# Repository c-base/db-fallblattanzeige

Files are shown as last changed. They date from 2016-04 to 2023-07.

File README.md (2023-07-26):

# db-fallblattanzeige
A Fallblattfahrzielanzeige of the Deutsche Bahn

  - [Demo video](https://www.youtube.com/watch?v=KNWKdqRn240)
  - [Hackaday Project](https://hackaday.io/project/9070-fallblattfahrzielanzeige-of-s-bahn-berlin)

Daemon ist unter: https://github.com/c-base/db-fallblattanzeige-web/roloboxd/

Web-Interface-Repo ist unter: https://github.com/c-base/db-fallblattanzeige-web

Architektur-Skizze: https://www.dropbox.com/s/tzrm99uehv5yp3d/whiteboard.png?dl=0

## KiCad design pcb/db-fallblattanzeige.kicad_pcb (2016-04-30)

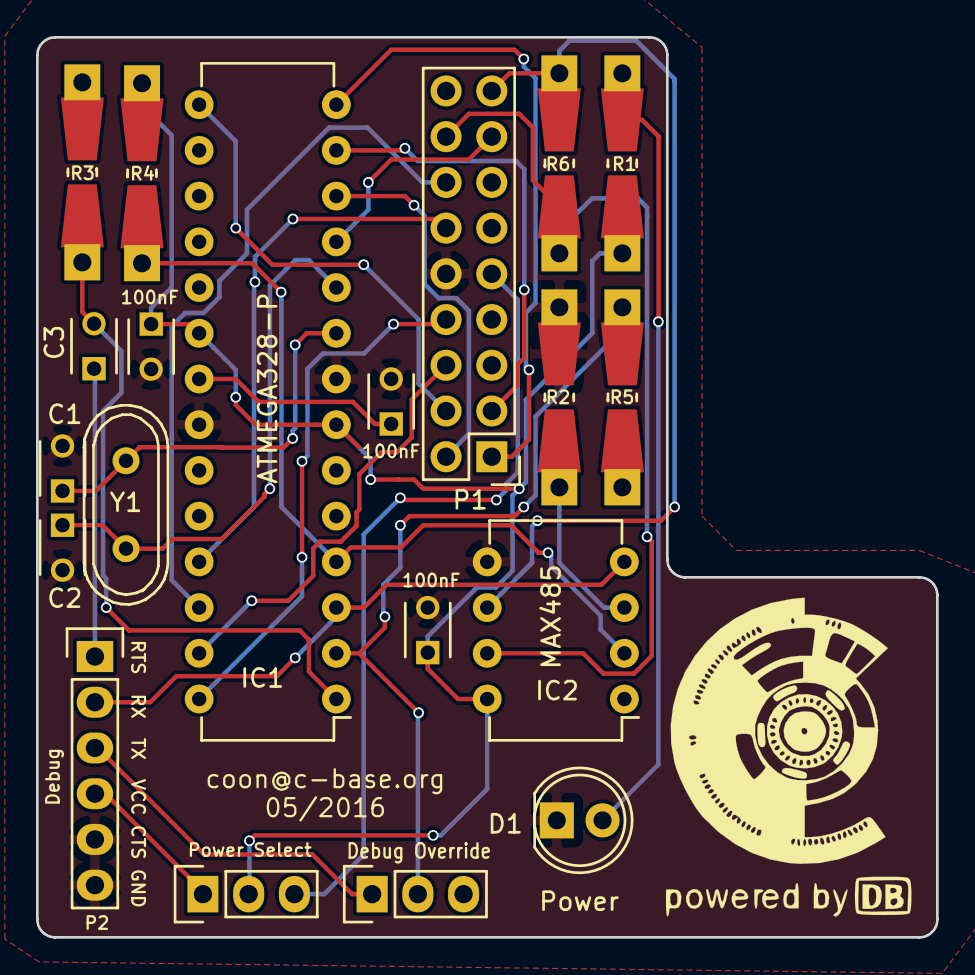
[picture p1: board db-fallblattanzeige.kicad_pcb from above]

Board: 2 copper layers, 50.0 x 50.0 mm, 20 parts (0 on the bottom side), 27 nets.

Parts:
100nF, 100nF#2, 100nF#3: C; C_Disc_D3_P2.5
C1, C2: 22pF; C_Disc_D3_P2.5
C3: 100nF; C_Disc_D3_P2.5
D1: Power LED (Green); LED-5MM
IC1: ATMEGA328-P; DIP-28_W7.62mm
IC2: MAX485; DIP-8_W7.62mm
JP1: Debug Override; Pin_Header_Straight_1x03
JP2: Power Select; Pin_Header_Straight_1x03
P1: ZiLOG_3562_FBM_V2.02
P2: FTDI_header; Pin_Header_Straight_1x06
R1: 150; Resistor_SMD+THTuniversal_0805to1206_RM10_HandSoldering
R2, R4: 4.7K; Resistor_SMD+THTuniversal_0805to1206_RM10_HandSoldering
R3: 10K; Resistor_SMD+THTuniversal_0805to1206_RM10_HandSoldering
R5: 1K; Resistor_SMD+THTuniversal_0805to1206_RM10_HandSoldering
R6: 120; Resistor_SMD+THTuniversal_0805to1206_RM10_HandSoldering
Y1: Crystal; Crystal_HC49-U_Vertical

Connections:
+5VA: JP2.1, P2.4
+5VD: JP2.3, P1.5
/BUS_MINUS: IC2.7, P1.11, R6.1
/BUS_PLUS: IC2.6, P1.9, R6.2
/IR_IN: IC1.11, P1.8
/Motor: IC1.15, P1.17
/PWR_IR1: IC1.26, P1.12
/PWR_IR2: IC1.25, P1.13
/SCL: IC1.28, P1.15
/SDA: IC1.27, P1.16
/SR_CP: IC1.13, P1.2
/SR_DATA: IC1.14, P1.1
/~SR_LATCH: IC1.12, P1.18
GND: 100nF.2, 100nF#2.2, 100nF#3.2, C1.2, C2.2, D1.1, IC1.8, IC1.22, IC2.5, P1.14, P2.5, P2.6, R2.2
unnamed: 100nF.1, IC1.21
unnamed: C1.1, IC1.9, Y1.1
unnamed: C2.1, IC1.10, Y1.2
unnamed: C3.1, P2.1
unnamed: C3.2, IC1.1, R3.2
unnamed: D1.2, R1.2
unnamed: IC1.2, JP1.2, R5.2
unnamed: IC1.3, IC2.4, P2.2
unnamed: IC1.4, IC2.2, R4.1
unnamed: IC1.5, IC2.3, R2.1
unnamed: IC2.1, R5.1
unnamed: JP1.1, P2.3
VCC: 100nF#2.1, 100nF#3.1, IC1.7, IC1.20, IC2.8, JP2.2, R1.1, R3.1, R4.2

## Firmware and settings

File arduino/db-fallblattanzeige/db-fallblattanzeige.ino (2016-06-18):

// DB-Fallblattanzeige 
// 18.06.2016
//
// Authors: uk, coon

// Pins
const int PIN_RS485_nRE  = 2;  // PD2 (Receive Enable)
const int PIN_RS485_DE   = 3;  // PD3 (Send Enable)
const int PIN_SENSORS_IN = 5;  // PD5 
const int PIN_SR_LATCH   = 6;  // PD6
const int PIN_SR_CP      = 7;  // PD7
const int PIN_SR_DATA    = 8;  // PB0
const int PIN_MOTOR      = 9;  // PB1
const int PIN_IR_ROTARY  = A2; // PC2
const int PIN_IR_ORIGIN  = A3; // PC3

// constants
const int I2C_EEPROM_ADDR = 0x50; // A0, A1, A2 are all on ground.
const int ORIGIN_OFFSET = 0; // TODO: read from EEPROM later!

enum SensorPhase {
  ODD,
  EVEN
};

int _myId = 0;

void waitForRotaryQuarters(SensorPhase phase, int quarters) {
  for(int i = 0; i < quarters; i++) {
    if(phase == EVEN) {    
      while(!digitalRead(PIN_SENSORS_IN)); // wait for first high
      while(digitalRead(PIN_SENSORS_IN));  // wait for low
      while(!digitalRead(PIN_SENSORS_IN)); // wait for second high 
    }
    else {
      while(digitalRead(PIN_SENSORS_IN));  // wait for first low
      while(!digitalRead(PIN_SENSORS_IN)); // wait for high
      while(digitalRead(PIN_SENSORS_IN));  // wait for second low
    }
  }
}

void flipCards(SensorPhase phase, int numCards) {
  digitalWrite(PIN_IR_ROTARY, HIGH);
  digitalWrite(PIN_MOTOR, LOW);
  
  for(int i = 0; i < numCards; i++)
    waitForRotaryQuarters(phase, 1);
    
  digitalWrite(PIN_MOTOR, HIGH);
  digitalWrite(PIN_IR_ROTARY, LOW);
}

void spinToOrigin(SensorPhase phase) {
  digitalWrite(PIN_IR_ORIGIN, HIGH);
  digitalWrite(PIN_MOTOR, LOW);

  while(digitalRead(PIN_SENSORS_IN));  // skip first high value
  while(!digitalRead(PIN_SENSORS_IN)); // wait for home  
  while(digitalRead(PIN_SENSORS_IN));  // wait for end of home
  
  digitalWrite(PIN_IR_ORIGIN, LOW);
  
  flipCards(phase, ORIGIN_OFFSET); // flip some additional cards, if needed
  
  digitalWrite(PIN_MOTOR, HIGH);
}

byte getDeviceBusAddress() {
  digitalWrite(PIN_SR_LATCH, LOW);
  delay(20);
  digitalWrite(PIN_SR_LATCH, HIGH);

  int address = 0;
  for(int i = 7; i >= 0; i--) {
    digitalWrite(PIN_SR_CP, LOW);
    delay(20);
    address |= digitalRead(PIN_SR_DATA) << i;
    digitalWrite(PIN_SR_CP, HIGH);
    delay(20);
  }

  return address;
}

void busEnable(bool enable) {
  digitalWrite(PIN_RS485_DE, enable ? HIGH : LOW);
}

void setup() {  
  digitalWrite(PIN_MOTOR, HIGH);
  digitalWrite(PIN_IR_ORIGIN, LOW);
  digitalWrite(PIN_IR_ROTARY, LOW);
  digitalWrite(PIN_RS485_nRE, LOW);
  digitalWrite(PIN_RS485_DE, LOW);
  
  pinMode(PIN_SENSORS_IN, INPUT);
  pinMode(PIN_SR_LATCH,   OUTPUT);
  pinMode(PIN_SR_CP,      OUTPUT);
  pinMode(PIN_SR_DATA,    INPUT);
  pinMode(PIN_MOTOR,      OUTPUT);
  pinMode(PIN_IR_ORIGIN,  OUTPUT);
  pinMode(PIN_IR_ROTARY,  OUTPUT);
  pinMode(PIN_RS485_nRE,  OUTPUT);
  pinMode(PIN_RS485_DE,   OUTPUT);

  busEnable(false);

  Serial.begin(9600);

  _myId = getDeviceBusAddress();
  Serial.print("Address: ");
  Serial.println(String(_myId, DEC));
  
  spinToOrigin(EVEN); // assume initial even
}

void loop() {
  if (Serial.available() > 0) {
    int id = Serial.readStringUntil('/').toInt();
    int numCards = Serial.readStringUntil('/').toInt();
    String strPhase = Serial.readStringUntil('\n');

    SensorPhase phase;
    if(strPhase.equals("EVEN"))
      phase = EVEN;
    else
      phase = ODD;

    if(id == _myId) {
      if(numCards > 0)
        flipCards(phase, numCards);
      else
        spinToOrigin(phase);
    }  
  }
}

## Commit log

2016-01-19 modified code for prototype pcb
2016-01-21 add basic I2C eeprom support but seems buggy...
    [db-fallblattanzeige.ino]
2016-01-23 device address can now be read
2016-01-25 add kicad project
    [db-fallblattanzeige.kicad_pcb, db-fallblattanzeige.sch]
2016-01-26 add some part to schematic
    [db-fallblattanzeige.sch]
2016-01-26 progress on schematic + add bus cable schematic
    [bus_cable.sch]
2016-01-27 add missing files
    [db-fallblattanzeige.sch]
2016-01-27 rename 'bus_cable' schematic to 'device_board'
    [db-fallblattanzeige.sch, device_board.sch]
2016-01-27 kicad: add some parts to device board
    [device_board.sch]
2016-01-30 add details like ac power and opto triac
    [address_board.sch, db-fallblattanzeige.sch, device_board.sch]
2016-01-30 add some connections to bus connector
    [device_board.sch]
2016-02-02 kicad: add BUS_UNKNOWN circuit
    [db-fallblattanzeige.sch, device_board.sch]
2016-02-03 kicad: corrected wiring
    [device_board.sch]
2016-02-09 added MAX810
    [db-fallblattanzeige.sch, device_board.sch]
2016-02-12 kicad: add some wires to MAX485
    [address_board.sch, db-fallblattanzeige.sch]
2016-02-14 kicad: finished RS485 wiring
    [db-fallblattanzeige.sch]
2016-02-14 kicad: rework of communication circuits
    [address_board.sch, db-fallblattanzeige.sch, device_board.sch]
2016-02-14 arduino: added... things
2016-02-14 add parking position to tx jumper
    [address_board.sch, db-fallblattanzeige.sch, device_board.sch]
2016-02-21 kicad: removed schmitt trigger
    [db-fallblattanzeige.sch]
2016-02-22 kicad: annotate and fixing errors
2016-02-22 kicad: forgotten files...
    [address_board.sch, db-fallblattanzeige.sch, device_board.sch]
2016-02-22 add netlist and footprint
    [db-fallblattanzeige.kicad_pcb, db-fallblattanzeige.sch]
2016-02-24 improved pcb layout
    [db-fallblattanzeige.kicad_pcb]
2016-02-26 fix crystal wiring, blocking caps
    [db-fallblattanzeige.kicad_pcb, db-fallblattanzeige.sch]
2016-02-27 arduino: add \n terminator
2016-02-28 kicad: completed routing
    [db-fallblattanzeige.kicad_pcb]
2016-02-28 add logo + FTDI header
    [db-fallblattanzeige.kicad_pcb]
2016-02-28 kicad: add some descriptions on silk
    [db-fallblattanzeige.kicad_pcb]
2016-02-28 kicad: add ground plane
    [db-fallblattanzeige.kicad_pcb]
2016-02-28 kicad: final version
    [db-fallblattanzeige.kicad_pcb, db-fallblattanzeige.sch]
2016-03-22 kicad: some work on revision 1
    [db-fallblattanzeige.kicad_pcb, db-fallblattanzeige.sch]
2016-03-22 corrected zilog footprint and silk
    [db-fallblattanzeige.kicad_pcb, db-fallblattanzeige.sch]
2016-04-04 finished revision 1
    [db-fallblattanzeige.kicad_pcb, db-fallblattanzeige.sch]
2016-04-30 fix 180° bug + R3/R4 swap (Rev2)
    [db-fallblattanzeige.kicad_pcb]
